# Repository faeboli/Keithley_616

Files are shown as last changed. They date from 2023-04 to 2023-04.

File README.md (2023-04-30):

# Keithley_616
Modification to Keithley 616 input buffer:
My keithkey 616 had the input mosfet Q101 broken,
I lately was not happy with it's performance, current leakage was 0.3pA, zero was drifty.
So my idea was to replace the input circuitry with a modern opamp, reading around the
perfect candidate was the LMC6081, a low leakage mosfet opamp.
In order to replace the input buffer, the zero circuit need to be reimplemented.
I have posted some pics in this eevblog thread:

https://www.eevblog.com/forum/repair/keithley-616-electrometer-input-stage-replacement/

The schematic is very simple, this part (PC361 in the box below):

616_Buf

will be replaced by this, C5 R6 need to be tuned manually:



I have also created a PCB project:

616_Buf_Pcb

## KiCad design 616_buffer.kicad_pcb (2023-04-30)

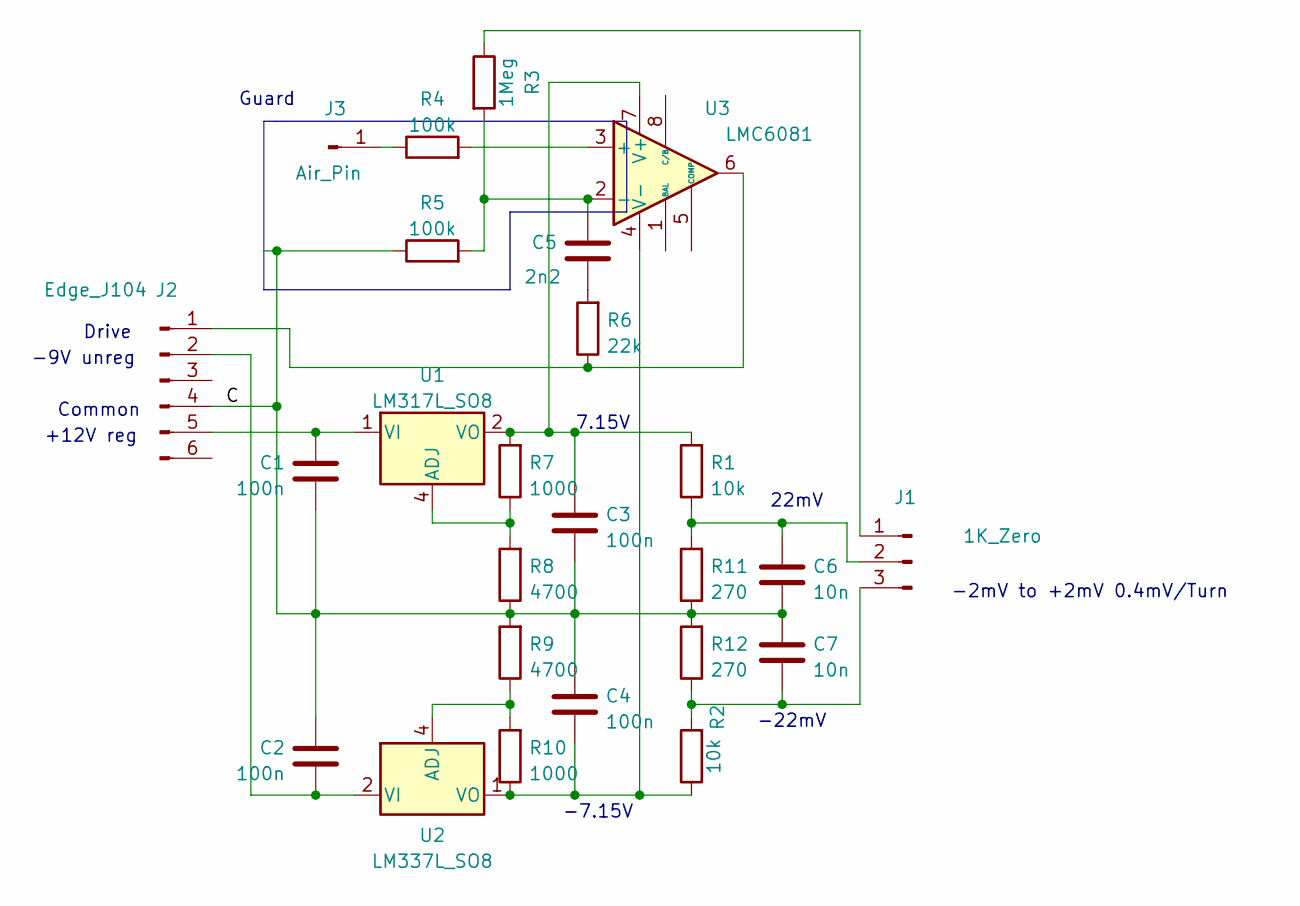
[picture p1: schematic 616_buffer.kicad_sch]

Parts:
C1, C2, C3, C4: 100n; C_0805_2012Metric
C5: 2n2; C_Rect_L10.0mm_W2.5mm_P7.50mm_MKS4
C6, C7: 10n; C_0805_2012Metric
J1: 1K_Zero; PinHeader_1x03_P2.54mm_Vertical
J2: Edge_J104; Hirose_DF63-6P-3.96DSA_1x06_P3.96mm_Vertical
J3: Air_Pin; TestPoint_Pad_D2.0mm
R1, R2: 10k; R_0805_2012Metric
R3: 1Meg; R_0805_2012Metric
R4, R5: 100k; R_0805_2012Metric
R6: 22k; R_0805_2012Metric
R7, R10: 1000; R_0805_2012Metric
R8, R9: 4700; R_0805_2012Metric
R11, R12: 270; R_0805_2012Metric
U1: LM317L_SO8; SOIC-8_3.9x4.9mm_P1.27mm
U2: LM337L_SO8; SOIC-8_3.9x4.9mm_P1.27mm
U3: LMC6081; SOIC-8_3.9x4.9mm_P1.27mm

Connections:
/C: C1.1, C2.2, C3.1, C4.2, C6.1, C7.2, J2.4, R5.1, R8.1, R9.2, R11.1, R12.2
unnamed: C1.2, J2.5, U1.1 (VI)
unnamed: C2.1, J2.2, U2.2 (VI), U2.3 (VI), U2.6 (VI), U2.7 (VI)
unnamed: C3.2, R1.2, R7.2, U1.2 (VO), U1.3 (VO), U1.6 (VO), U1.7 (VO), U3.7 (V+)
unnamed: C4.1, R2.1, R10.1, U2.1 (VO), U3.4 (V-)
unnamed: C5.1, R6.2
unnamed: C5.2, R3.2, R5.2, U3.2 (-)
unnamed: C6.2, J1.2, R1.1, R11.2
unnamed: C7.1, J1.3, R2.2, R12.1
unnamed: J1.1, R3.1
unnamed: J2.1, R6.1, U3.6
unnamed: J3.1, R4.1
unnamed: R4.2, U3.3 (+)
unnamed: R7.1, R8.2, U1.4 (ADJ)
unnamed: R9.1, R10.2, U2.4 (ADJ)

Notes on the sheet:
-7.15V
Guard
Common
+12V reg
7.15V
-2mV to +2mV 0.4mV/Turn
22mV
-9V unreg
-22mV
Drive

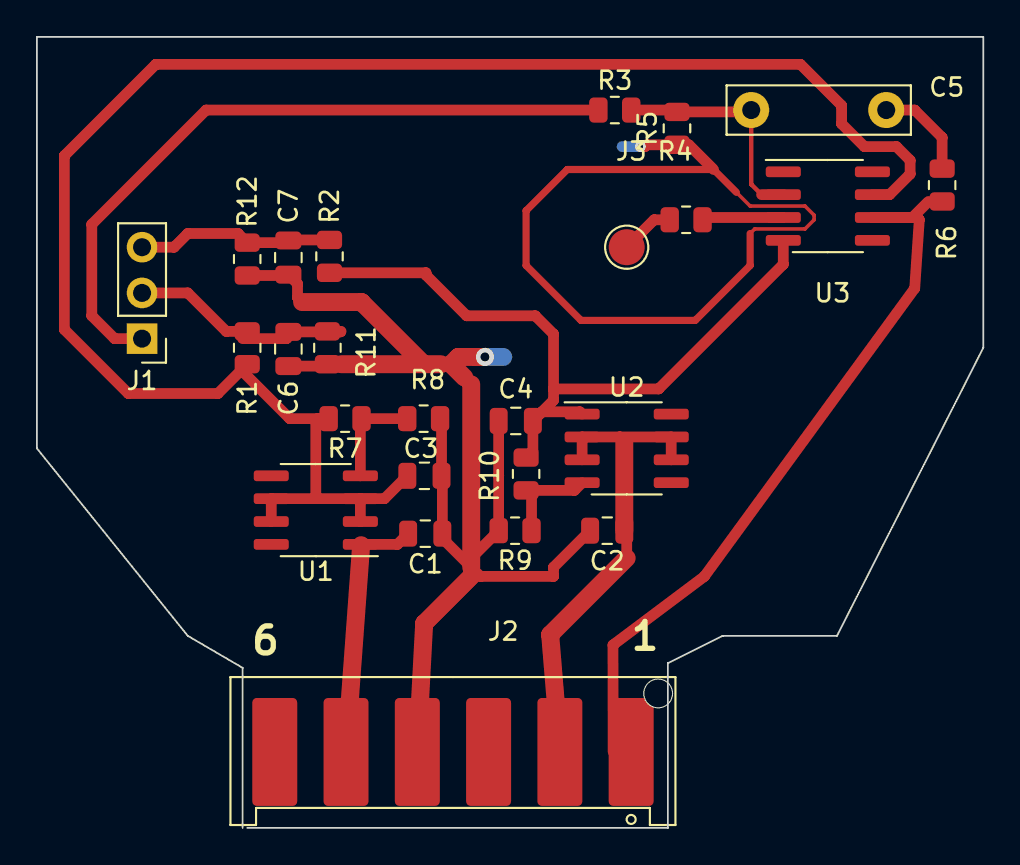
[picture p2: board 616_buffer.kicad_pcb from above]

Board: 2 copper layers, 52.6 x 43.9 mm, 25 parts (0 on the bottom side), 15 nets.

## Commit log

2023-03-20 Fixed zero connector pinout
    [616_buffer.kicad_pcb, 616_buffer.kicad_sch]
2023-03-20 Updated gerbers with correct zero connector pinout
    [616_buffer-B_Cu.gbr, 616_buffer-B_Mask.gbr, 616_buffer-B_Silkscreen.gbr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]
2023-04-06 Fixed edge connector spacing
    [616_buffer-B_Cu.gbr, 616_buffer-B_Mask.gbr, 616_buffer-B_Silkscreen.gbr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]
2023-04-06 removed old directory
    [616_buffer-B_Cu.gbr, 616_buffer-B_Mask.gbr, 616_buffer-B_Silkscreen.gbr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]
2023-04-30 Update schematic
    [616_buffer-B_Cu.gbr, 616_buffer-B_Mask.gbr, 616_buffer-B_Silkscreen.gbr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]
